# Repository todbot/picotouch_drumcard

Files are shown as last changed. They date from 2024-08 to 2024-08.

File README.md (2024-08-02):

# picotouch_drumcard

Playing card-sized (2.5"x3.5") sequencer / synth / USB / MIDI touch controller

Successor to the [picotouch_bizcard MIDI controller](https://github.com/todbot/picotouch_bizcard)

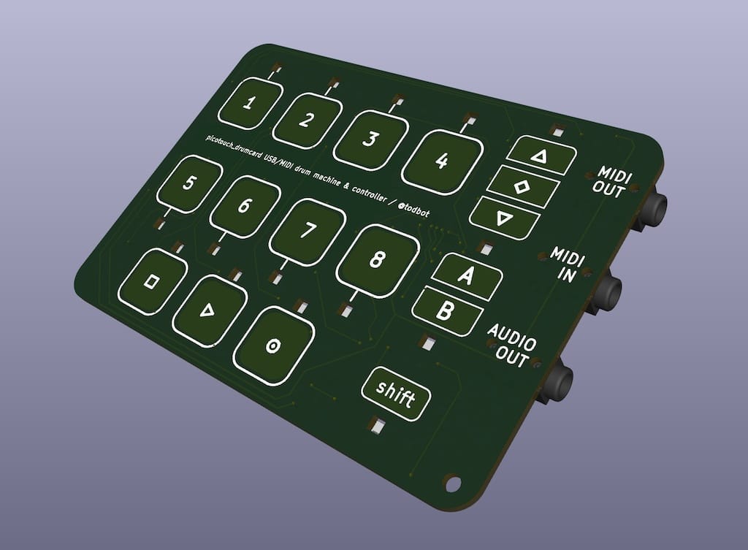
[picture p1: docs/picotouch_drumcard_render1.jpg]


## Features

* 17 capacitive touch pads arranged in a step-sequencer layout
* 15 reverse-mounted LEDs as status / touch indicators
* TRS-A MIDI In and Out
* Audio out (via 12-bit PWM)
* Battery powered, with lipo battery charging circuit
* Powered by Raspberry Pi Pico board
* Programmable with CircuitPython, Arduino, etc.

# Example code

* Drum sequencer + synth
* MIDI controller
* Macropad
* USB-MIDI interface

# 

https://github.com/user-attachments/assets/234cb804-bad1-4454-a92b-b1dc36a663cc

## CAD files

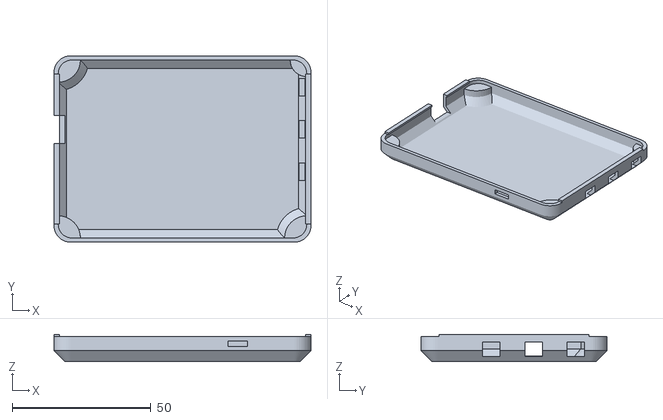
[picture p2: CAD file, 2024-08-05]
enclosure/picotouch_drumcard_case.stl
92.5 x 67.1 x 9.80

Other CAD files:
enclosure/picotouch_drumcard.f3d
enclosure/picotouch_drumcard_case v15.f3z

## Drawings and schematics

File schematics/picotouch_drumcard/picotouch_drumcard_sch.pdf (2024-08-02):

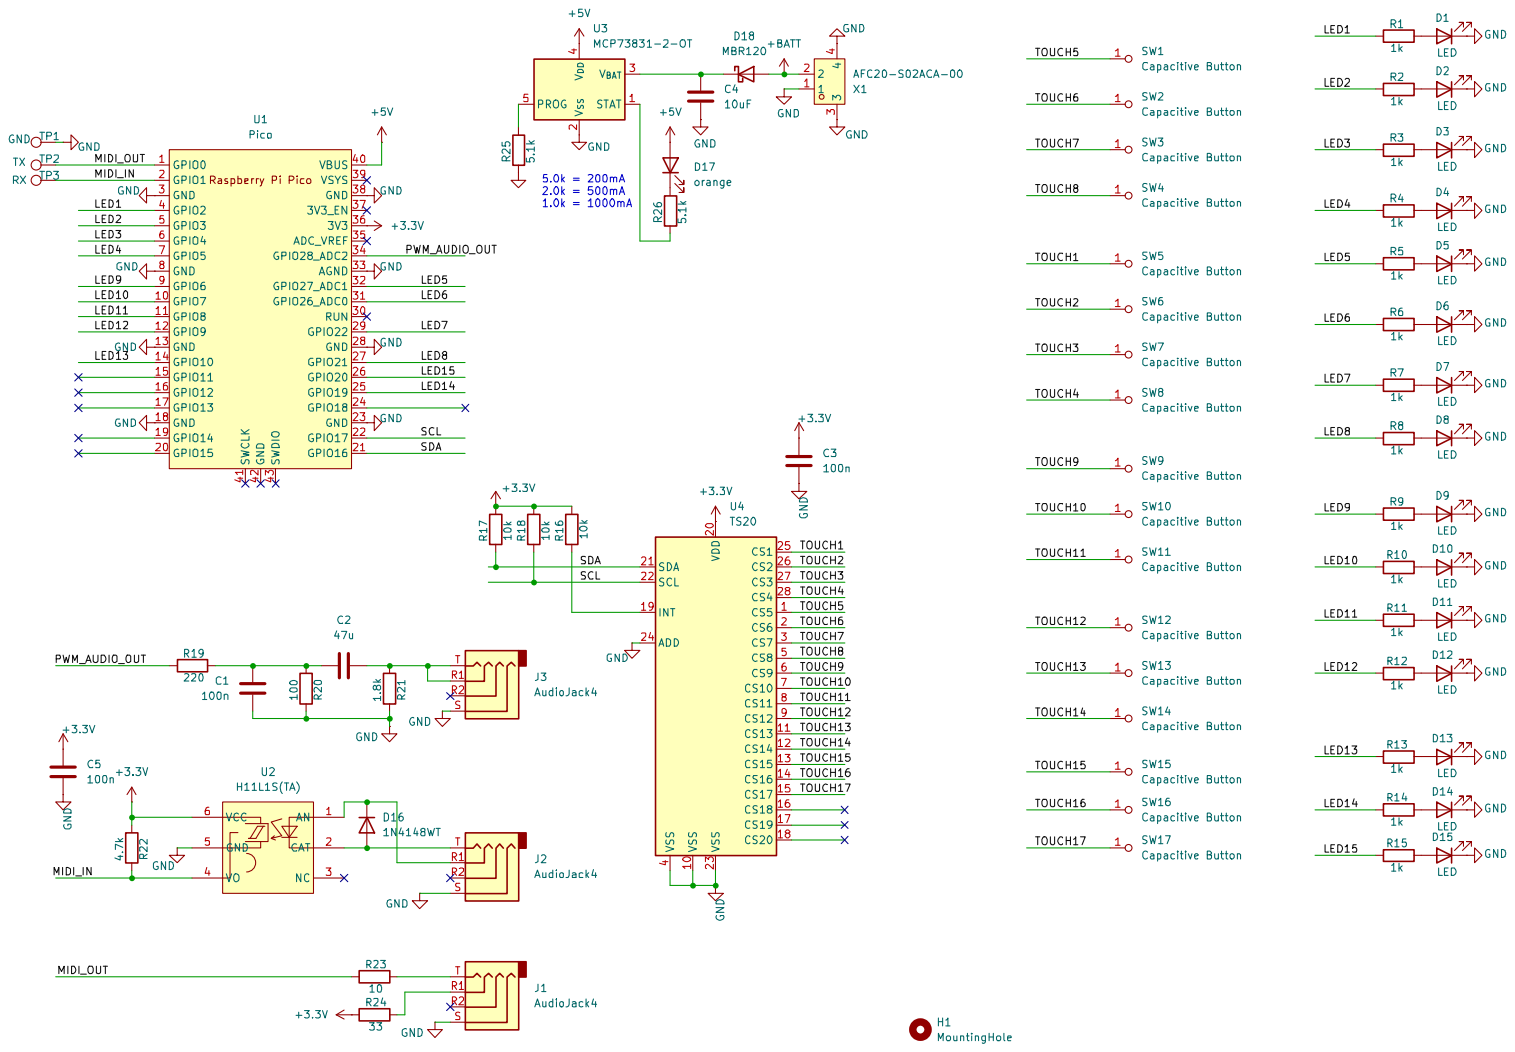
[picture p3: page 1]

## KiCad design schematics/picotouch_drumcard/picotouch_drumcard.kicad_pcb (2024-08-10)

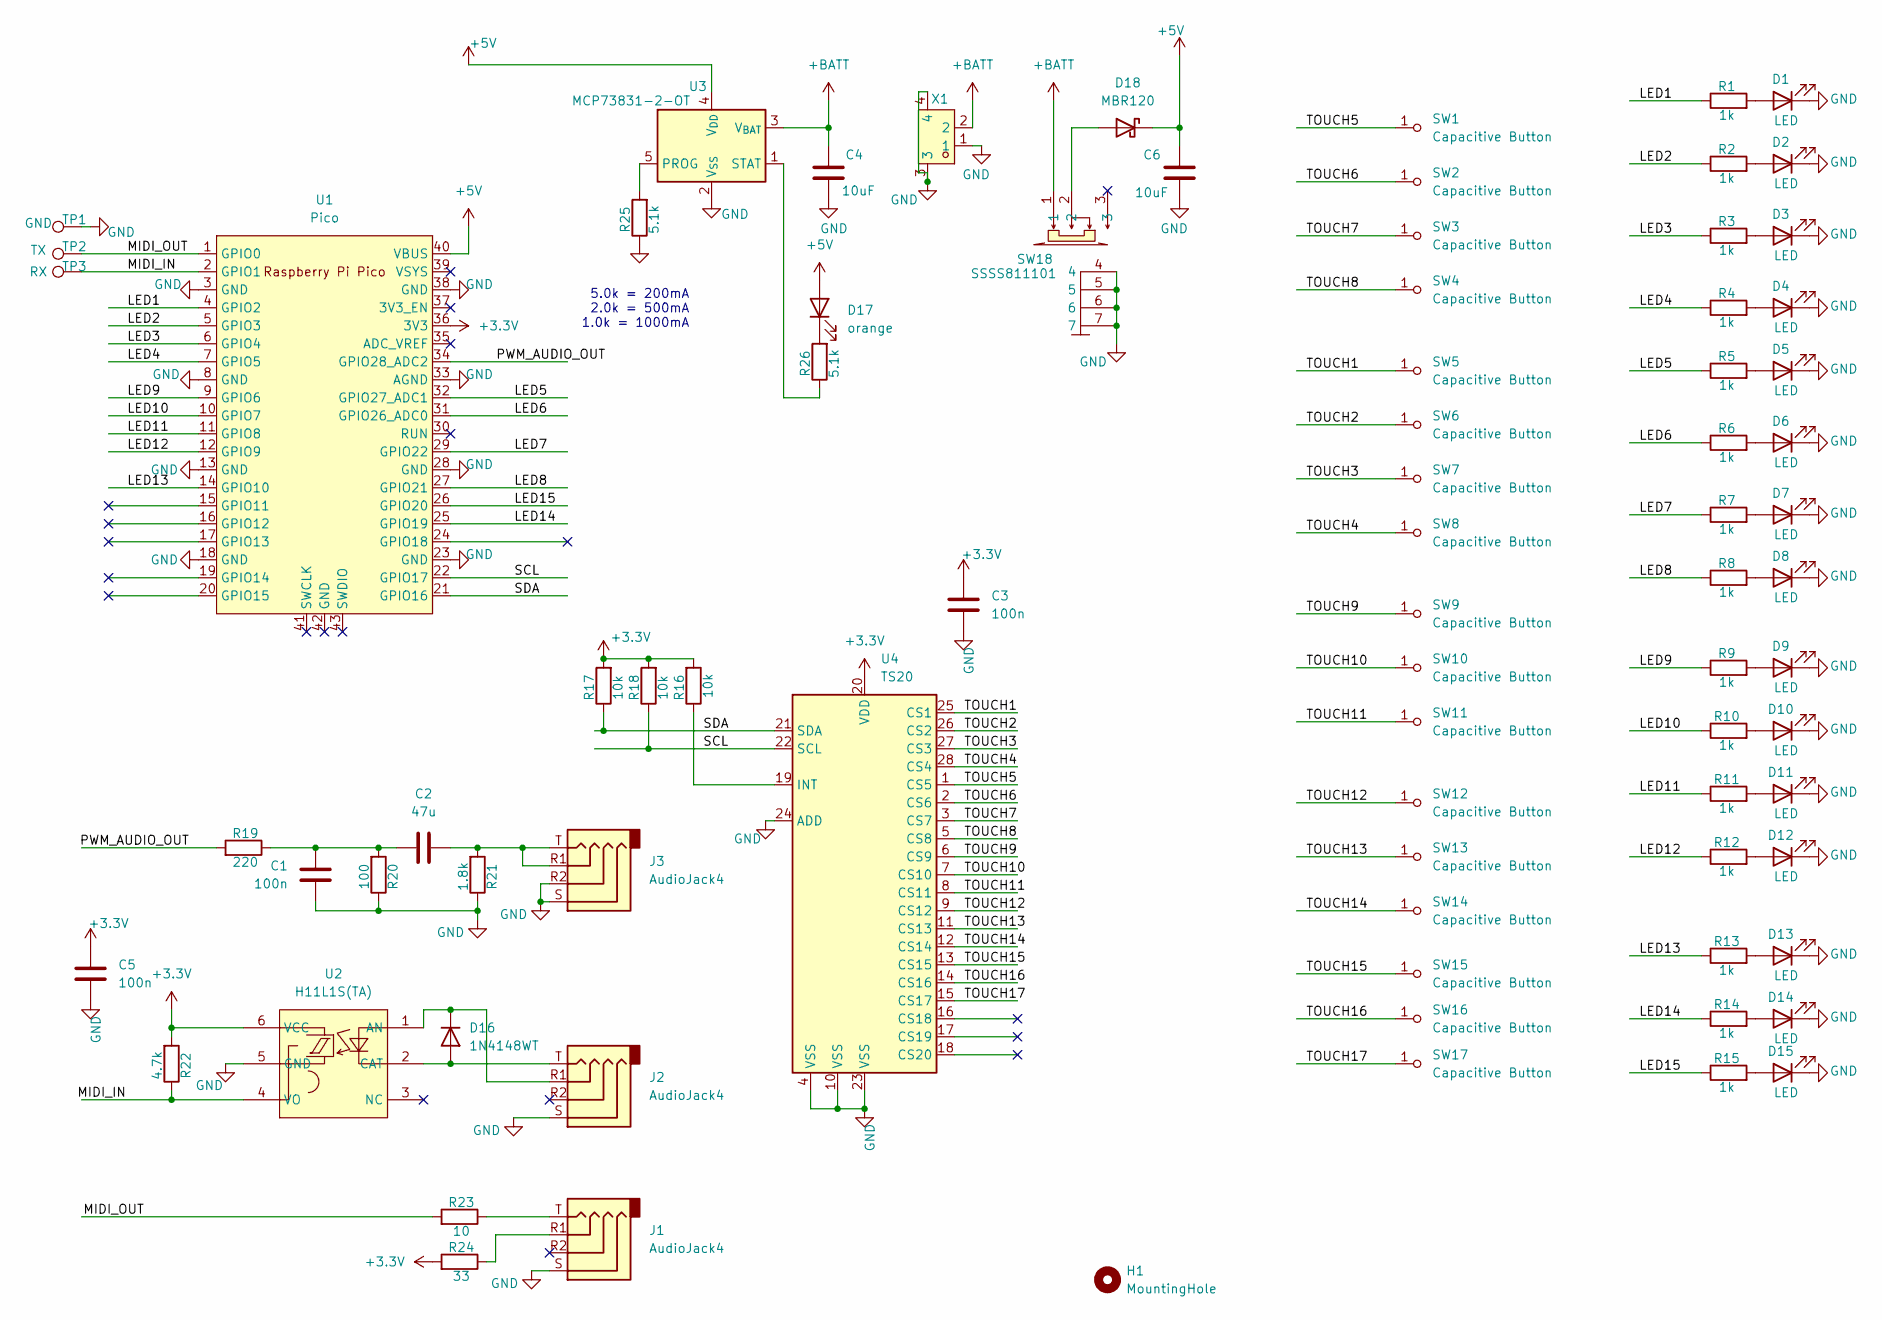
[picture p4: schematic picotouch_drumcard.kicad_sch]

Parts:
C1, C3, C5: 100n; C_0603_1608Metric
C2: 47u; C_0603_1608Metric
C4, C6: 10uF; C_0603_1608Metric
D1, D2, D3, D4, D5, D6, D7, D8, D9, D10, D11, D12, D13, D14, D15: LED; LED1206_LTST-C230KRKT-cutout; LCSC C125107
D16: 1N4148WT; D_SOD-123F; LCSC Part C64898
D17: orange; LED_0603_1608Metric
D18: MBR120; D_SOD-123F; LCSC Part C130880
H1: MountingHole; MountingHole_2.5mm
J1: AudioJack4; Jack_3.5mm_PJ320D_Horizontal; LCSC C431535
J2, J3: AudioJack4; Jack_3.5mm_PJ320D_Horizontal; LCSC Part C431535
R1, R2, R3, R4, R5, R6, R7, R8, R9, R10, R11, R12, R13, R14, R15: 1k; R_0603_1608Metric
R16, R17, R18: 10k; R_0603_1608Metric
R19: 220; R_0603_1608Metric
R20: 100; R_0603_1608Metric
R21: 1.8k; R_0603_1608Metric
R22: 4.7k; R_0603_1608Metric
R23: 10; R_0603_1608Metric
R24: 33; R_0603_1608Metric
R25, R26: 5.1k; R_0603_1608Metric
SW1, SW2, SW3, SW4, SW5, SW6, SW7, SW8, SW9, SW10, SW11: Capacitive Button; Pad-CapacitiveTouch
SW12, SW13, SW14, SW15, SW16, SW17: Capacitive Button; Pad-CapacitiveTouch-SparkFun-10x5mm-roundrect
SW18: SSSS811101; SW-SMD_SSSS811101; LCSC Part C109335
TP1: GND; TestPoint_Pad_D2.0mm
TP2: TX; TestPoint_Pad_D2.0mm
TP3: RX; TestPoint_Pad_D2.0mm
U1: Pico; RPi_Pico_SMD
U2: H11L1S(TA); SMD-6_L7.3-W6.5-P2.54-LS10.2-BL; LCSC Part C78589
U3: MCP73831-2-OT; SOT-23-5; LCSC Part C424093
U4: TS20; TSSOP-28_4.4x9.7mm_P0.65mm; LCSC Part C95876
X1: AFC20-S02ACA-00; CONN-SMD_AFC20-S02ACA-00; LCSC Part C2764211

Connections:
+3.3V: C3.1, C5.1, R16.2, R17.2, R18.2, R22.2, R24.2, U1.36 (3V3), U2.6 (VCC), U4.20 (VDD)
+5V: C6.1, D17.2 (A), D18.1 (K), U1.40 (VBUS), U3.4 (V_{DD})
+BATT: C4.1, SW18.1, U3.3 (V_{BAT}), X1.2
/LED1: R1.1, U1.4 (GPIO2)
/LED2: R2.1, U1.5 (GPIO3)
/LED3: R3.1, U1.6 (GPIO4)
/LED4: R4.1, U1.7 (GPIO5)
/LED5: R5.1, U1.32 (GPIO27_ADC1)
/LED6: R6.1, U1.31 (GPIO26_ADC0)
/LED7: R7.1, U1.29 (GPIO22)
/LED8: R8.1, U1.27 (GPIO21)
/LED9: R9.1, U1.9 (GPIO6)
/LED10: R10.1, U1.10 (GPIO7)
/LED11: R11.1, U1.11 (GPIO8)
/LED12: R12.1, U1.12 (GPIO9)
/LED13: R13.1, U1.14 (GPIO10)
/LED14: R14.1, U1.25 (GPIO19)
/LED15: R15.1, U1.26 (GPIO20)
/MIDI_IN: R22.1, TP3.1, U1.2 (GPIO1), U2.4 (VO)
/MIDI_OUT: R23.2, TP2.1, U1.1 (GPIO0)
/PWM_AUDIO_OUT: R19.2, U1.34 (GPIO28_ADC2)
/SCL: R18.1, U1.22 (GPIO17), U4.22 (SCL)
/SDA: R17.1, U1.21 (GPIO16), U4.21 (SDA)
/TOUCH1: SW5.1 (A), U4.25 (CS1)
/TOUCH2: SW6.1 (A), U4.26 (CS2)
/TOUCH3: SW7.1 (A), U4.27 (CS3)
/TOUCH4: SW8.1 (A), U4.28 (CS4)
/TOUCH5: SW1.1 (A), U4.1 (CS5)
/TOUCH6: SW2.1 (A), U4.2 (CS6)
/TOUCH7: SW3.1 (A), U4.3 (CS7)
/TOUCH8: SW4.1 (A), U4.5 (CS8)
/TOUCH9: SW9.1 (A), U4.6 (CS9)
/TOUCH10: SW10.1 (A), U4.7 (CS10)
/TOUCH11: SW11.1 (A), U4.8 (CS11)
/TOUCH12: SW12.1 (A), U4.9 (CS12)
/TOUCH13: SW13.1 (A), U4.11 (CS13)
/TOUCH14: SW14.1 (A), U4.12 (CS14)
/TOUCH15: SW15.1 (A), U4.13 (CS15)
/TOUCH16: SW16.1 (A), U4.14 (CS16)
/TOUCH17: SW17.1 (A), U4.15 (CS17)
GND: C1.2, C3.2, C4.2, C5.2, C6.2, D1.1 (K), D2.1 (K), D3.1 (K), D4.1 (K), D5.1 (K), D6.1 (K), D7.1 (K), D8.1 (K), D9.1 (K), D10.1 (K), D11.1 (K), D12.1 (K), D13.1 (K), D14.1 (K), D15.1 (K), J1.S, J2.S, J3.R2, J3.S, R20.1, R21.1, R25.1, SW18.4, SW18.5, SW18.6, SW18.7, TP1.1, U1.3 (GND), U1.8 (GND), U1.13 (GND), U1.18 (GND), U1.23 (GND), U1.28 (GND), U1.33 (AGND), U1.38 (GND), U2.5 (GND), U3.2 (V_{SS}), U4.4 (VSS), U4.10 (VSS), U4.23 (VSS), U4.24 (ADD), X1.1, X1.3, X1.4
unnamed: C1.1, C2.2, R19.1, R20.2
unnamed: C2.1, J3.R1, J3.T, R21.2
unnamed: D1.2 (A), R1.2
unnamed: D2.2 (A), R2.2
unnamed: D3.2 (A), R3.2
unnamed: D4.2 (A), R4.2
unnamed: D5.2 (A), R5.2
unnamed: D6.2 (A), R6.2
unnamed: D7.2 (A), R7.2
unnamed: D8.2 (A), R8.2
unnamed: D9.2 (A), R9.2
unnamed: D10.2 (A), R10.2
unnamed: D11.2 (A), R11.2
unnamed: D12.2 (A), R12.2
unnamed: D13.2 (A), R13.2
unnamed: D14.2 (A), R14.2
unnamed: D15.2 (A), R15.2
unnamed: D16.2 (A), J2.T, U2.2 (CAT)
unnamed: D16.1 (K), J2.R1, U2.1 (AN)
unnamed: D17.1 (K), R26.2
unnamed: D18.2 (A), SW18.2
unnamed: J1.R1, R24.1
unnamed: J1.T, R23.1
unnamed: R25.2, U3.5 (PROG)
unnamed: R26.1, U3.1 (STAT)
unnamed: R16.1, U4.19 (INT)

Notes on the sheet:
5.0k = 200mA 2.0k = 500mA 1.0k = 1000mA

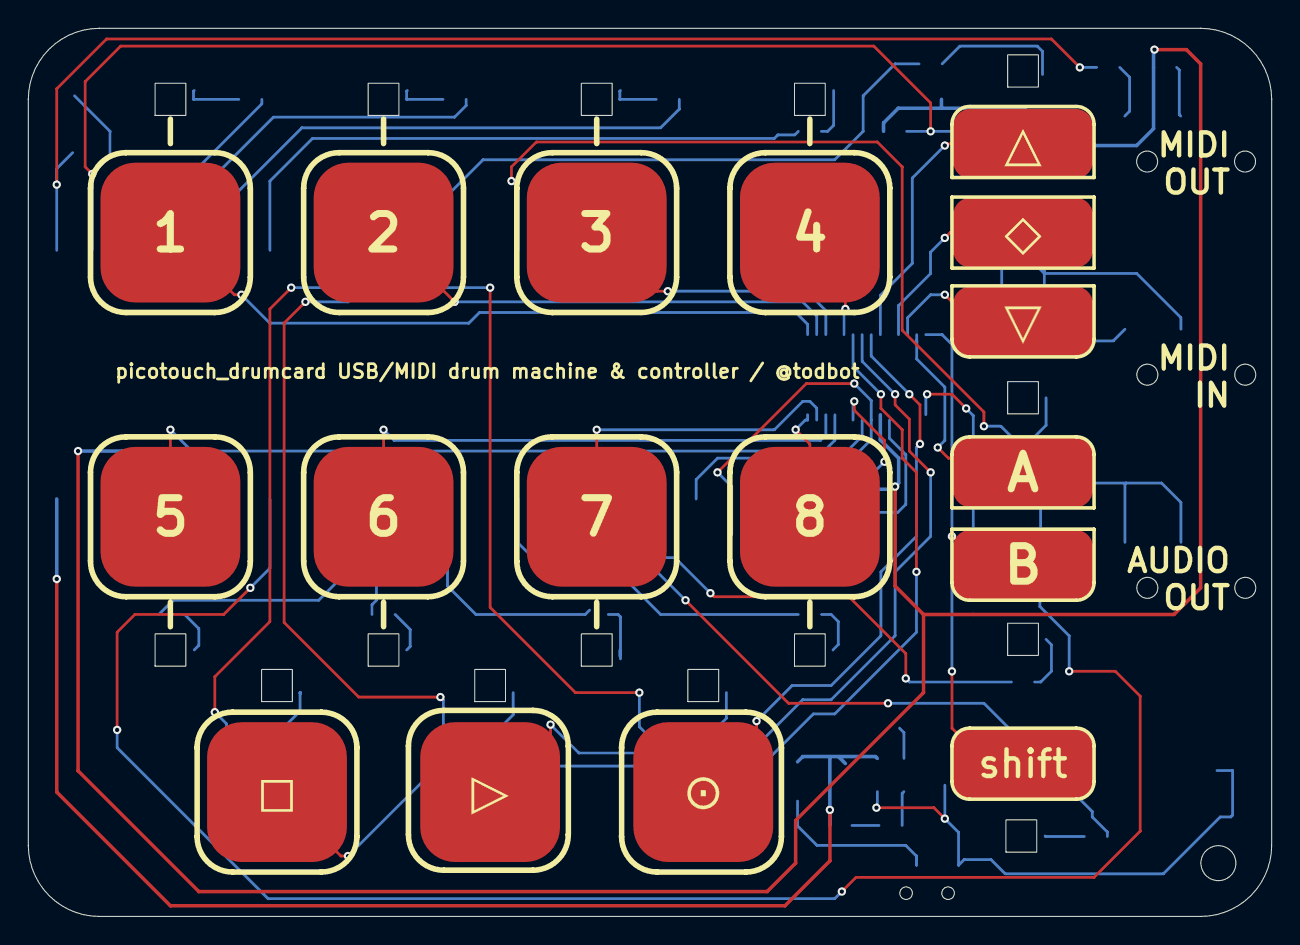
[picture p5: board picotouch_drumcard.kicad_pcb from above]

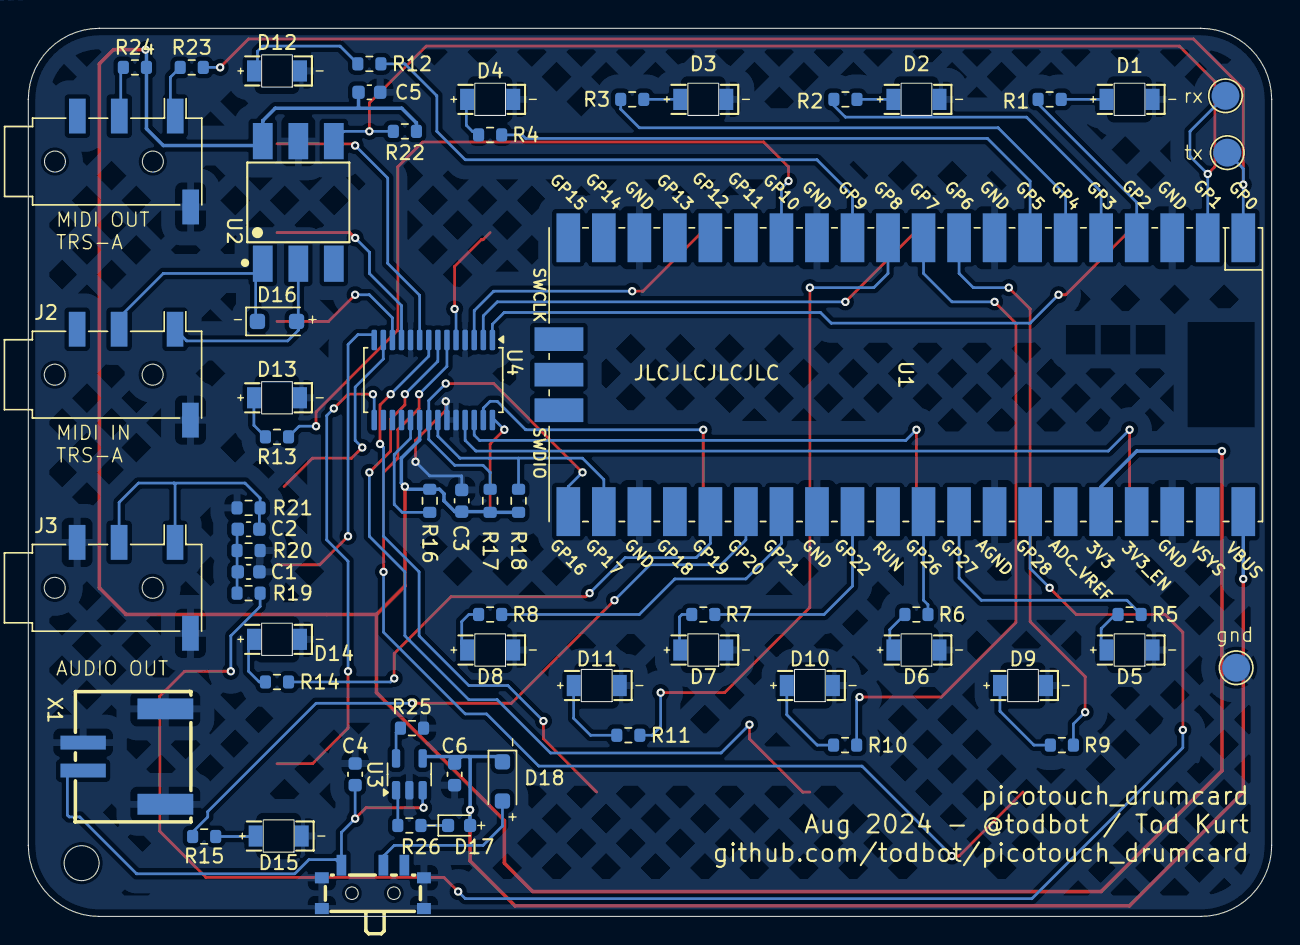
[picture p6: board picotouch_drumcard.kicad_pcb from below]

Board: 2 copper layers, 88.9 x 63.5 mm, 80 parts (62 on the bottom side), 67 nets.

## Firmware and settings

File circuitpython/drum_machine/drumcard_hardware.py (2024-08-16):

import time
import random
import board
import busio
import digitalio
import pwmio
import audiopwmio, audiomixer, audiocore, synthio
import usb_midi
import ulab.numpy as np

import tmidi
import ts20

i2c_sda_pin = board.GP16
i2c_scl_pin = board.GP17
midi_out_pin = board.GP0
midi_in_pin = board.GP1
audio_pin = board.GP28
pico_pwr_pin = board.GP23

      
# fmt: off
led_pins = (
    board.GP2, board.GP3, board.GP4, board.GP5,     # 1,2,3,4
    board.GP27, board.GP26, board.GP22, board.GP21, # 5,6,7,8
    board.GP6, board.GP7, board.GP8,                # 9 (stop), 10 (play), 11 (rec)
    board.GP9, board.GP10, board.GP19, board.GP20   # 12 (up/dn), 13 (A), 14 (B), 15 (shift)
)
num_leds = len(led_pins)

# oops getting "RuntimeError: Internal resource(s) in use"
# when trying to PWM all the LED pins
# so will just on/off them for now

# map LEDs to as close an a clockwise radial circle as possible
demo_led_map = (0,1,2,3, 11,12,13,14, 7,10,6,9,5,8,4)  # circle around clockwise

# # map idealized LED number to physical LED pin number
# led_map = ( 4, 5, 6, 7,  # pads 1-4
#             0, 1, 2, 3,  # pads 5-8
#             8, 9, 10,    # pads stop, play, rec
#            )
            
# map touch pad index to LED
# (some multiple pads map to a single LED, some touch inputs are not wired)
pad_to_led = (
    0, 1, 2, 3,     # 5,6,7,8
    4, 5, 6, 7,     # 1,2,3,4
    8, 9 ,10,       # stop, play, rec
    11, 11, 11,     # up, center, down
    12, 13, 14,     # A, B, shift
    None, None, None,     # not wired
)
# fmt: on


class DrumCardHardware:

    LED_STOP = 8
    LED_PLAY = 9
    LED_REC = 10

    # symbolic names for padids
    PAD_1 = 0
    PAD_2 = 1
    PAD_3 = 2
    PAD_4 = 3
    PAD_5 = 4
    PAD_6 = 5
    PAD_7 = 6
    PAD_8 = 7
    PAD_STOP = 8    
    PAD_PLAY = 9
    PAD_REC = 10
    PAD_UP = 11
    PAD_MID = 12
    PAD_DOWN = 13
    PAD_A = 14
    PAD_B = 15
    PAD_SHIFT = 16

    def __init__(self, sample_rate=22050, num_voices=8):
        self.sample_rate = sample_rate
        self.num_voices = num_voices
        i2c = busio.I2C(scl=i2c_scl_pin, sda=i2c_sda_pin, frequency=400_000)
        self.ts20 = ts20.TS20(i2c)

        self.uart = busio.UART(tx=midi_out_pin, rx=midi_in_pin, baudrate=31250, timeout=0.0001)
        self.midi_usb = tmidi.MIDI(midi_in=usb_midi.ports[0], midi_out=usb_midi.ports[1])
        self.midi_uart = tmidi.MIDI(midi_in=self.uart)

        # set up the synth->audio system
        self.audio = audiopwmio.PWMAudioOut(audio_pin)
        self.mixer = audiomixer.Mixer(voice_count=num_voices, sample_rate=sample_rate,
                                      channel_count=1, bits_per_sample=16, samples_signed=True,
                                      buffer_size=2048) 
        self.leds = []
        for pin in led_pins:
            print("pin:", pin)
            led = digitalio.DigitalInOut(pin)
            led.switch_to_output(value=False)
            self.leds.append(led)

    def start_synth(self, level=0.75):
        self.synth = synthio.Synthesizer(sample_rate=self.sample_rate)
        self.audio.play(self.mixer)
        self.mixer.voice[0].level = level # turn down the volume a bit since this can get loud
        self.mixer.voice[0].play(self.synth)
        
        # set up the synth
        self.wave_saw = np.linspace(30000,-30000, num=256, dtype=np.int16)  # default squ is too clippy
        amp_env = synthio.Envelope(sustain_level=0.8, release_time=0.1, attack_time=0.001)
        self.synth.envelope = amp_env
        
    def start_sampleplayer(self):
        pass

    def set_led(self, n, val):
        self.leds[n].value = val

    def set_led2(self, n, val):
        """
        Set an LED according to  padid number:
        0-7 : pads 1-8
        9 : 
        """
        self.leds[pad_to_led[n]].value =  val
        
    def set_leds(self, val):
        for l in self.leds: l.value = val

    def pad_to_led(self, i):
        return pad_to_led[i]

    def read_touch(self):
        touches = self.ts20.read_touches()
        # swizzle first four and second four to match layout weirdness I did
        touches[0:4], touches[4:8] = touches[4:8],touches[0:4]
        self.touches = touches
        return self.touches

    def update(self):
        self.read_touches()

    def startup_demo(self, n=2, t=0.02):
        print("picotouch_drumcard: startup demo")

        for j in range(n):
            for i in range(num_leds):
                self.set_led(demo_led_map[i], True)
                f = synthio.midi_to_hz(random.randint(32,72))
                note = synthio.Note(frequency=f)
                self.synth.press(note)
                time.sleep(t)
                self.set_led(demo_led_map[i], False)
                self.synth.release(note)
                time.sleep(t)
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

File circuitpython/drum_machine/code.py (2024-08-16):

# SPDX-FileCopyrightText: Copyright (c) 2024 Tod Kurt
# SPDX-License-Identifier: MIT
"""
picotouch_drumcard_drum_machine.py --
31 Jul 2024 - @todbot / Tod Kurt
Part of https://github.com/todbot/picotouch_drumcard
"""

import asyncio
import gc
import time
import random
import synthio
import tmidi

from adafruit_ticks import ticks_ms, ticks_diff, ticks_add

from drumcard_hardware import DrumCardHardware

from drum_kits import find_kits, load_drumkit
from drum_sequencer import DrumSequencer


midi_base = 42
pad_to_midi = ( 0, 2, 4, 5, 7, 9, 10, 12)
        
kits = find_kits()
kit_index = 0
waves, num_trigs = load_drumkit(kits, kit_index)
print("kits:",kits, "\nnum_trigs:", num_trigs)

hw = DrumCardHardware()
hw.start_synth()
#hw.startup_demo()
hw.start_sampleplayer()

pad_lit_millis = 100
pads_lit = [False] * num_trigs

# callback function called by sequencer
def drum_on(trigid, seqpos=None):
    #print("drum_on:",trigid, seqpos)
    voice = hw.mixer.voice[trigid]   # get mixer voice
    voice.play(waves[trigid], loop=False)
    hw.set_led(trigid, True)
    pads_lit[trigid] = True
    #gc.collect()

# callback function called by sequencer
def drum_off(trigid, seqpos=None):
    #print("drum_off:", trigid)
    pass

patterns = DrumSequencer.load_patterns("/saved_patterns.json")
seq = DrumSequencer(120, patterns, trig_on=drum_on, trig_off=drum_off)

seq.change_pattern(1)
seq.playing = True

last_padlit_millis = ticks_ms()
last_debug_millis = ticks_ms()
rec_mode = False
rec_held = False

touches = []

# # play a drum sample, either by sequencer or pressing pads
# def play_drum(num, on=True):
#     voice = hw.mixer.voice[num]   # get mixer voice
#     if on:
#         voice.play(waves[num], loop=False)
#         pass
#     else:
#         voice.stop()

async def seq_updater():
    while True:
        seq.update()
        await asyncio.sleep(0.001)
        
async def midi_handler():
    while True:
        await asyncio.sleep(0.001)
        while msg := hw.midi_uart.receive() or hw.midi_usb.receive():
            if msg.type == tmidi.NOTE_ON:
                chan = msg.channel
                note = msg.data0
                vel = msg.data1
                print('NoteOn: Ch: {} Note: {} Vel:{}'.format(chan, note, vel))
                hw.synth.press( note )
            elif msg.type == tmidi.NOTE_OFF:
                chan = msg.channel
                note = msg.data0
                vel = msg.data1
                print('NoteOff: Ch: {} Note: {} Vel:{}'.format(chan, note, vel))
                hw.synth.release( note )
            elif msg.type == tmidi.PITCH_BEND:
                chan = msg.channel
                pbval = (msg.data1 << 7) | msg.data0
                print("PitchBend: Ch: {} Bend: {}".format(chan, pbval))
            elif msg.type == tmidi.CC:
                chan = msg.channel
                ccnum = msg.data0
                ccval = msg.data1
                print('CC Ch: {}, Num: {} Val: {}'.format(chan, ccnum, ccval))
            elif msg.type == tmidi.CHANNEL_PRESSURE:
                chan = msg.channel
                press_val = msg.data0
                print('Ch Pressure: Ch: {}, Val: {}'.format(chan, press_val))
            elif msg.type == tmidi.SYSTEM_RESET:
                print('System reset')
            else:
                print("unknown message:",msg)

async def ui_handler():
    global rec_mode, rec_held, touches, kit_index, waves, num_trigs
    trig_pressed = False
    last_padlit_millis = ticks_ms()
    last_touches = hw.read_touch()
    
    while True:
        await asyncio.sleep(0.05)
        # update playstate
        hw.set_led(hw.LED_PLAY, seq.playing)
        hw.set_led(hw.LED_REC, rec_mode or rec_held)

        now_millis = ticks_ms()
        # turn off any triggered pads after a while
        if ticks_diff(now_millis, last_padlit_millis) > pad_lit_millis:
            last_padlit_millis = now_millis
            for i in range(num_trigs):
                if pads_lit[i]:
                    pads_lit[i] = False
                    hw.set_led(i, False)

        touches = hw.read_touch()
        if hw.bad_touch(): continue
        
        # read touchpad
        for i, t in enumerate(touches):
            if i > 15: continue  # not wired inputs
            if t and not last_touches[i]:  # pressed
                ledi = hw.pad_to_led(i)
                hw.set_led(ledi, t)
                if i < 8:  # is drumpad, not control
                    trig_pressed = True
                    if rec_mode:
                        seq.set_trig(i)
                        drum_on(i)
                    else:
                        drum_on(i)  # normal playing
                elif i == hw.PAD_PLAY:
                    seq.playing = not seq.playing
                elif i == hw.PAD_STOP:
                    seq.playing = False
                    seq.pos = 0
                elif i == hw.PAD_REC:
                    rec_held = True
                elif i == hw.PAD_A:
                    seq.change_pattern(seq.patt_index+1)
                elif i == hw.PAD_B:
                    seq.change_pattern(seq.patt_index-1)
                elif i == hw.PAD_UP:
                    kit_index = (kit_index + 1) % len(kits['kit_names'])
                    waves, num_trigs = load_drumkit(kits, kit_index)
                    
            
            if not t and last_touches[i]: # released
                ledi = hw.pad_to_led(i)
                hw.set_led(ledi, t)
                if i< 8:
                    if rec_held:
                        seq.clear_trigs(i)
                        
                elif i == hw.PAD_REC:
                    rec_held = False
                    if trig_pressed:
                        trig_pressed = False
                    else:
                        rec_mode = not rec_mode
                
        last_touches = touches

        
async def debug_handler():
    while True:
        print("debug: ", touches)
        await asyncio.sleep(1)
        
    #     #print("%.2f %.2f" % (time.monotonic(), dt), touches)
        

    # # debugging touch output
    # if ticks_diff(now_millis, last_debug_millis) > 100:
    #     last_debug_millis = now_millis
    #     #print("%.2f %.2f" % (time.monotonic(), dt), touches)
    #     print("%.2f %.2f" % (time.monotonic(), dt))

print("picotouch_drumcard_drum_machine: ready")

async def main():
    task2 = asyncio.create_task(ui_handler())
    task3 = asyncio.create_task(midi_handler())
    task4 = asyncio.create_task(seq_updater())
    task5 = asyncio.create_task(debug_handler())
    await asyncio.gather(task2, task3, task4, task5)

asyncio.run(main())

# #gc.disable()

# while True:
#     dt = time.monotonic()
#     midi_handler()
#     seq.update()
    
#     # update playstate
#     hw.set_led(hw.LED_PLAY, seq.playing)
#     hw.set_led(hw.LED_REC, rec_mode or rec_held)

#     touches = hw.read_touch()
#     if hw.bad_touch(): continue
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

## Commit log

2024-08-01 added protection diodes
    [picotouch_drumcard.kicad_pcb, picotouch_drumcard.kicad_sch]
2024-08-01 fix button labels
    [picotouch_drumcard.kicad_pcb]
2024-08-02 tuning layout
    [picotouch_drumcard.kicad_pcb, picotouch_drumcard.kicad_sch]
2024-08-02 add missing cap on opto
    [picotouch_drumcard.kicad_pcb, picotouch_drumcard.kicad_sch]
2024-08-02 dangit forgot power switch
    [picotouch_drumcard.kicad_pcb, picotouch_drumcard.kicad_sch]
2024-08-02 add missing cap to charger circuit, nudge around charger to fit
    [picotouch_drumcard.kicad_pcb, picotouch_drumcard.kicad_sch]
2024-08-05 add 3d printable enclosure and CAD files
    [picotouch_drumcard.f3d, picotouch_drumcard_case v15.f3z]
2024-08-10 sigh more fixes to charging circuit
    [picotouch_drumcard.kicad_pcb, picotouch_drumcard.kicad_sch]
2024-08-10 audio out needs Ring2 to Gnd for headphones to work (I knew this)
    [picotouch_drumcard.kicad_pcb, picotouch_drumcard.kicad_sch]
2024-08-13 hwtest sends midi on both uart & usb
